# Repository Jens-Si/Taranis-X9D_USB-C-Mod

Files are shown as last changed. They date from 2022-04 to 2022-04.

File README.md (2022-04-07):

# Taranis-X9D_USB-C-Mod

I was always looking for a microUSB cable. Therefore, I have developed a small circuit board to equip my Taranis X9D with a USB-C socket.

<p align="center">
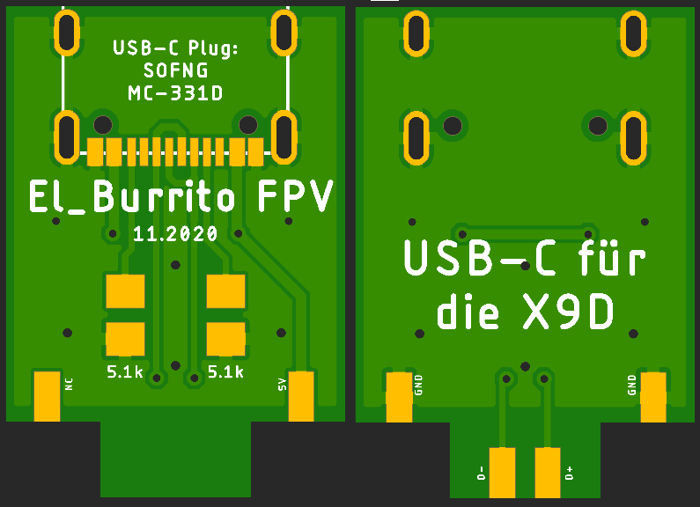
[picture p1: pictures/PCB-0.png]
Screenshot PCB
  
</p>

## Instalation
- Open the radio and take out the middle PCB with the USB connector.
- Desolder and replace the USB-PCB with the new one.
- Take a small file and widen the hole for the USB connector.

<p align="center">
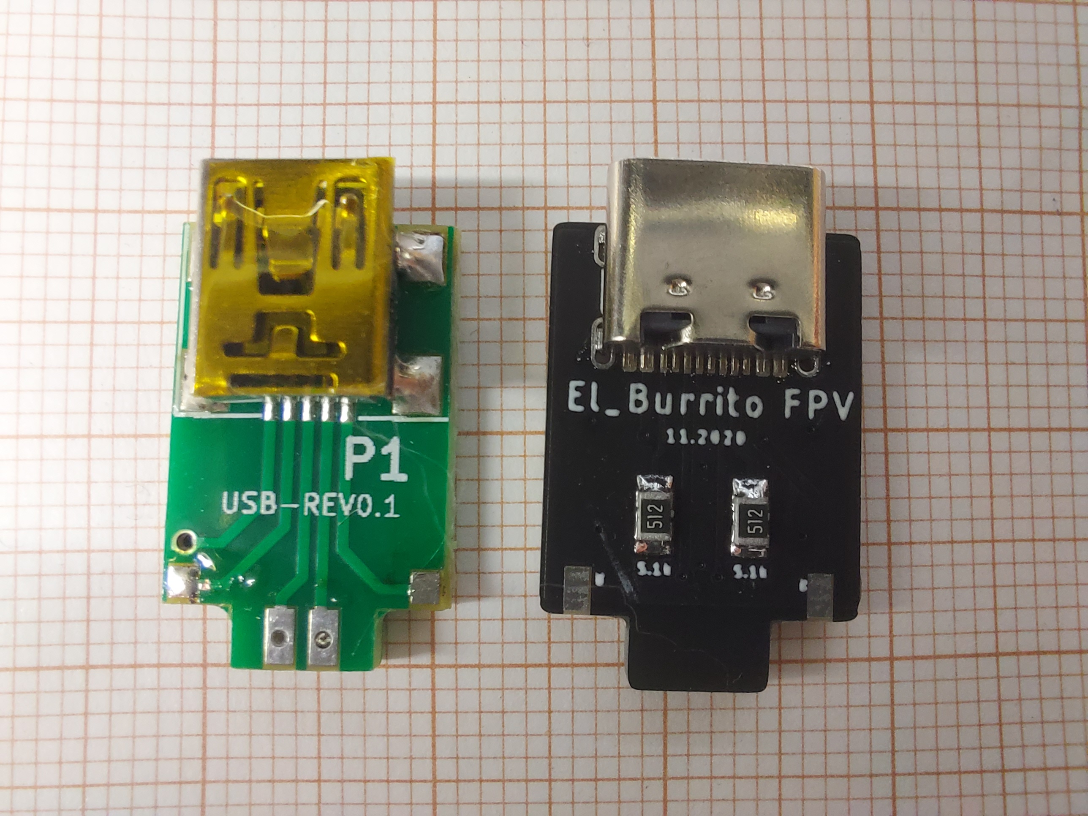
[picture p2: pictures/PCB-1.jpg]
old and new PCB
  
  <br /> Old and new PCB
</p>

<p align="center">
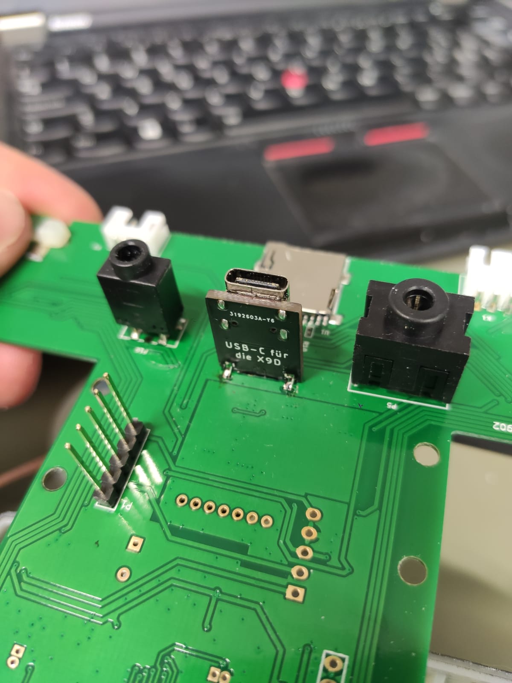
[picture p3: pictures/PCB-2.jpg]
PCB install 1
  
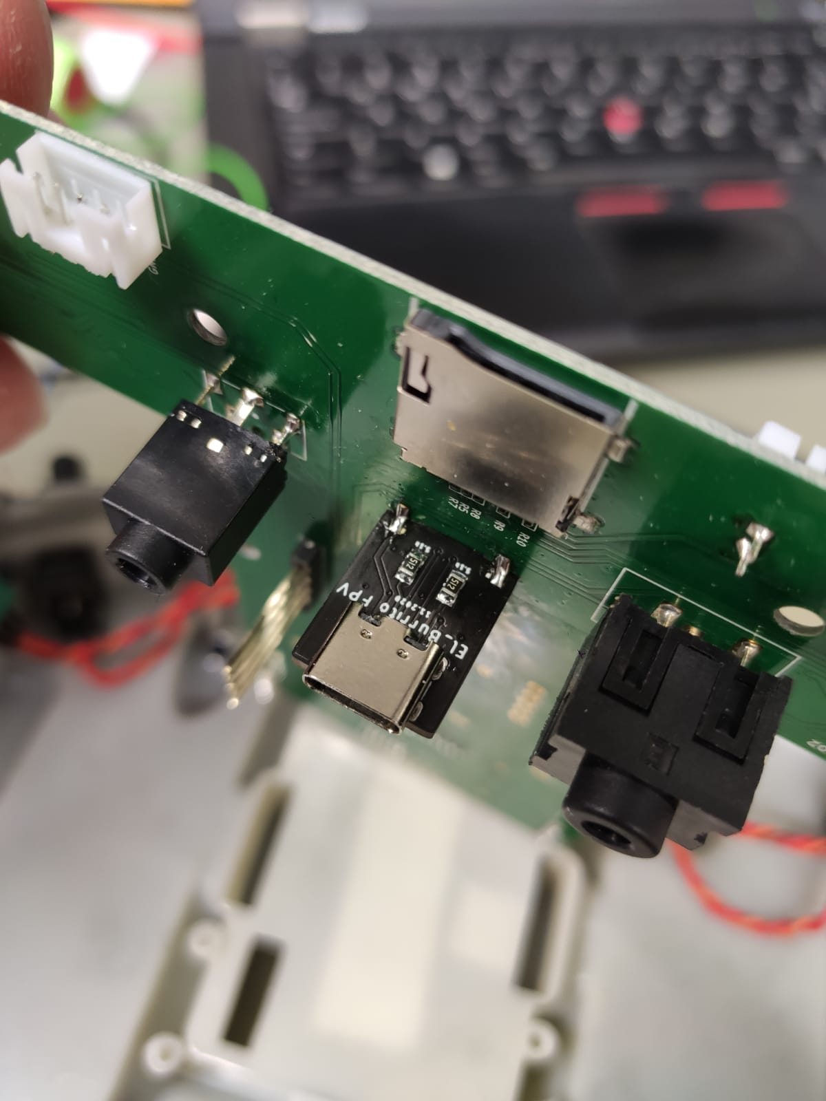
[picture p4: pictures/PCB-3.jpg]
PCB install 2
  
  <br /> Installation of the new PCB
</p>
<p align="center">
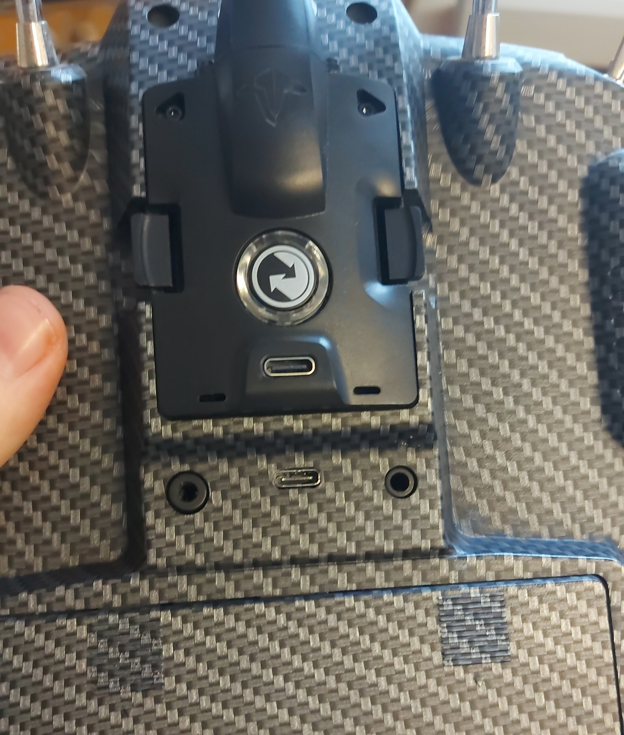
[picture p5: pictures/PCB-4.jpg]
back of radio
  
  <br /> the "new" back of the radio :D
</p>

## PCB
In the folder "PCB" you can see the EAGLE project, if you want to have a look at it. <br />
Or you can upload the .zip file at places like JLCPCB and order the PCB straight away.

## BOM
You only need three components. The USB-C plug and 2x 5.1kOhm 0805 SMD Resistor. <br />
The folder "BOM" contains the datasheet for the USB-C plug, if you have to source a different one...

- 1x https://lcsc.com/product-detail/USB-Connectors_SOFNG-MC-311D_C136423.html
- 2x https://lcsc.com/product-detail/Chip-Resistor-Surface-Mount_UNI-ROYAL-Uniroyal-Elec-0805W8J0512T5E_C26023.html

## ...
i still have a few PCB's left... ;)

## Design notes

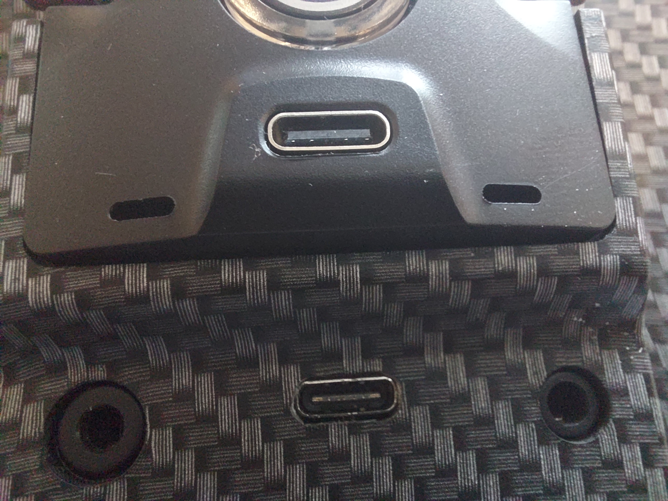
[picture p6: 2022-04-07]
pictures/PCB-5.jpg

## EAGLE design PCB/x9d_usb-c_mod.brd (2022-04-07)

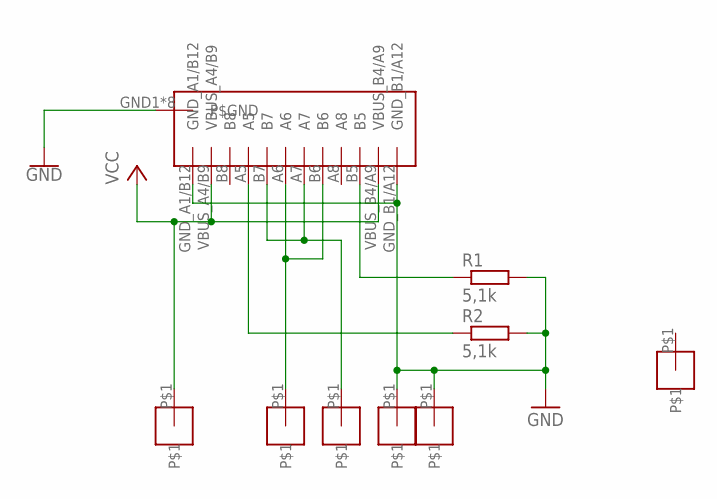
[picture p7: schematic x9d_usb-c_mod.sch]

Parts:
GND1: MOTORPADPAD_1X2; PAD_1X2
MID1, MID2, MID3, MID4, MID6: MOTORPADPAD_1X2; PAD_1X2
R1, R2: 5,1k; R0805
U$1: USB-C_2.0SOFNG_MC-331D; USB-C_MC-331D

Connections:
GND: GND1.P$1, MID1.P$1, R1.2, R2.2, U$1.GND1 (P$GND), U$1.GND2 (P$GND), U$1.GND3 (P$GND), U$1.GND4 (P$GND), U$1.GND5 (P$GND), U$1.GND6 (P$GND), U$1.GND7 (P$GND), U$1.GND8 (P$GND), U$1.GND_A1/B12, U$1.GND_B1/A12
unnamed: MID6.P$1, U$1.A7, U$1.B7
unnamed: MID3.P$1, U$1.A6, U$1.B6
unnamed: R1.1, U$1.B5
unnamed: R2.1, U$1.A5
VCC: MID2.P$1, U$1.VBUS_A4/B9, U$1.VBUS_B4/A9

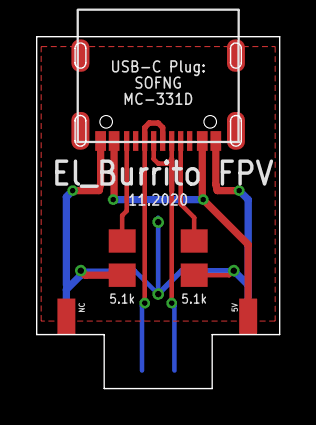
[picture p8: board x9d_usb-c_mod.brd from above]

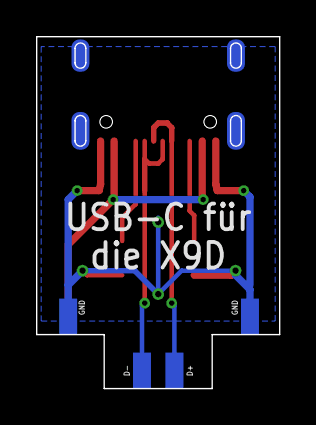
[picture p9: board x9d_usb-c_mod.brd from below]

Board: 2 copper layers, 13.5 x 19.6 mm, 9 parts (4 on the bottom side), 6 nets.

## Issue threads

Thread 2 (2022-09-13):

X9D SE 2019

Difo96, 2022-09-13:
I want to made the same mod on my Taranis X9D Plus SE 2019, the issue is that the 2019 verion has the USB and the two Jacks on the same PCB, can i use your mod simply moving the USB-C PCB in another location, remove the original Mini USB connector and use four wires to connect your USB-C PCB to the original PCB?!
P.S. in the 2019 version the USB connector is also used for battery charging.

Jens-Si, 2022-12-21:
i don't have this radio, so this is just speculation. It shoud be possible if the charging only uses 5V and no QC or PD.
Maybe connect the USB-C and test everything bevore you remove the original one.

Difo96, 2022-12-21:
Ehi! Hi! At the end I bought a new USB board to test how it works, i
studied a bit and did a lot of research so I was able to design a new one
with a USB-C port and a connector for a secondary USB-C port.
From the board I have 5 volts when it is plugged to the USB charger so it
is not a QC or PD device, I already have the new boards but I'm waiting to
install them because I want to make a video about it.

Thanks for your reply.
Matteo.

Il giorno mer 21 dic 2022 alle ore 08:50 El_Burrito <
***@***.***> ha scritto:

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

Closed 2022-12-21.

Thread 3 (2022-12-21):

Ripped 5V pad

EcN000, 2022-12-21:
I ripped my 5V pad off on my taranis board...is 5V needed in order for this to function? Any idea where I can tap for 5V?

Jens-Si, 2022-12-21:
I don’t remember the 5V being used for anything. So it should not be a problem.

EcN000, 2022-12-21:
Okay thanks, because I do see your PCB connecting 5V...will re-assemble and
see. Thank you for your designs btw.

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

Jens-Si, 2022-12-21:
Test the USB-Storage and USB-Controler funktion. If something is not working, then you can solder a wire to the 5. pad here:
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

EcN000, 2022-12-21:
Tried without 5V and it didn't work. Hooked it up to the 5V worked! thank
you!

On Wed, Dec 21, 2022 at 12:17 AM El_Burrito ***@***.***>
wrote:

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

Closed 2022-12-21.

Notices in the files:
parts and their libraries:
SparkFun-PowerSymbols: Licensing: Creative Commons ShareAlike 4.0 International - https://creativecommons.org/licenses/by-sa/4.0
